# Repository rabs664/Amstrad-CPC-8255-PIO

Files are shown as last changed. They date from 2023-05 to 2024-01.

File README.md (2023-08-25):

# Amstrad CPC 8255 PIO
Simple 8255 PIO board compatible with the Amstrad CPC and MX4 connector.

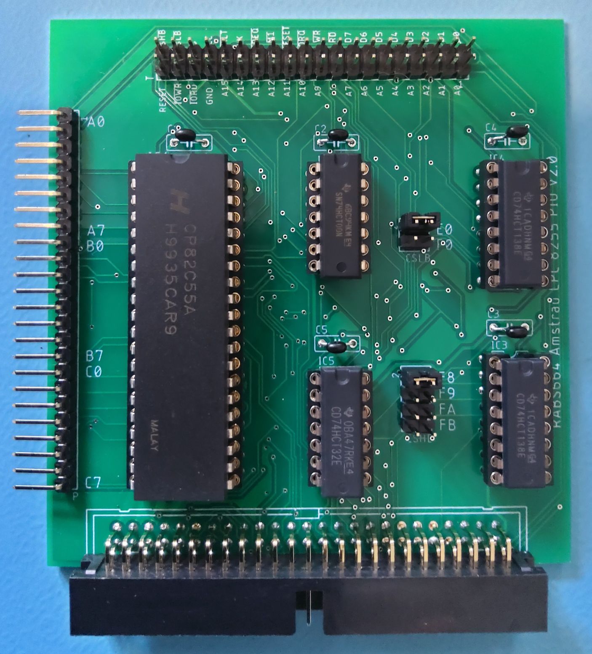
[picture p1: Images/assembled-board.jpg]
readme_pic1


## Objective
Prototyping board to Learn about the 8255 PIO, and how to write Z80 assembly using an Amstrad CPC.

## Background
Part of a number of modular cards using Z80 associated peripherals and the Amstrad CPC.

## Backplane
[CPC Amstrad Expansion Backplane by revaldinho](https://github.com/revaldinho/cpc_ram_expansion/wiki/CPC-Expansion-Backplane)

## IO Addressing
The IO Address can be selected using two sets of jumpers (CS_HB and CS_LB), supporting the following base address.

* F8E0 and F8F0
* F9E0 and F9F0
* FAE0 and FAF0
* FBE0 and FBF0

See [CPC Wiki IO Port Summary](https://www.cpcwiki.eu/index.php/I/O_Port_Summary) for a list of known IO ports used on the Amstrad CPC.

## Testing
The 8255 PIO board has been built and has been tested on an Amstrad CPC 6128.

## PCBs
PCBs are available from [Seeed Studio V2.0](https://www.seeedstudio.com/Amstrad-CPC-8255-PIO-g-1393845) or [Seeed Studio V3.1](https://www.seeedstudio.com/Simple-8255-PIO-board-compatible-with-the-Amstrad-CPC-and-MX4-connector-V3--g-1396645)

## Components
This [Digi-Key List](https://www.digikey.co.uk/en/mylists/list/ZWWIHRPLO7 ) contains all components excluding the 8255 which was purchased from EBay.

Note the right angled header for the port connections was not available at the time of producing this list but all other components were in stock for shipping immediately.

## Assembler
[RASM](https://github.com/EdouardBERGE/rasm)

## Resources
[Zed80 Website](http://zed80.com/Z80-RETRO/index_Home.html)

[CPCWiki](https://www.cpcwiki.eu/index.php/Main_Page)

Z80 Application by James W Coffron ISBN 0-89588-094-6

## Acknowledgements
[@revaldinho](https://github.com/revaldinho)

Don Prefontaine 

Peter Murray

[@EdouardBERGE](https://github.com/EdouardBERGE)

# Release History
## Version 2.0
* First Release
## Version 3.1
* KiCad created version of PCB.

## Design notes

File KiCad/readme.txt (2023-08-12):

This folder contains files associated with the use of KiCad to create the schematics and PCB.

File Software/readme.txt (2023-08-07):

This folder contains software associated with the Amstrad CPC 8255 PIO.

piotst04.bas is a test program written in BASIC.

piotst02.asm is an equivalent program written in Z80 Assembly (using RASM) and using CPC Firmware routines. piotst02.dsk is the disk created from this.

very-quick-test.txt contains some simple instructions to undertake a very quick test to see if the PIO is working.

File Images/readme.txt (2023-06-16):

This folder contains some images of the Amstrad CPC 8255 PIO board and associated test programs.

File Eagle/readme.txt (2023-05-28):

This folder contains files associated with the use of Eagle to create the schematics and PCB.

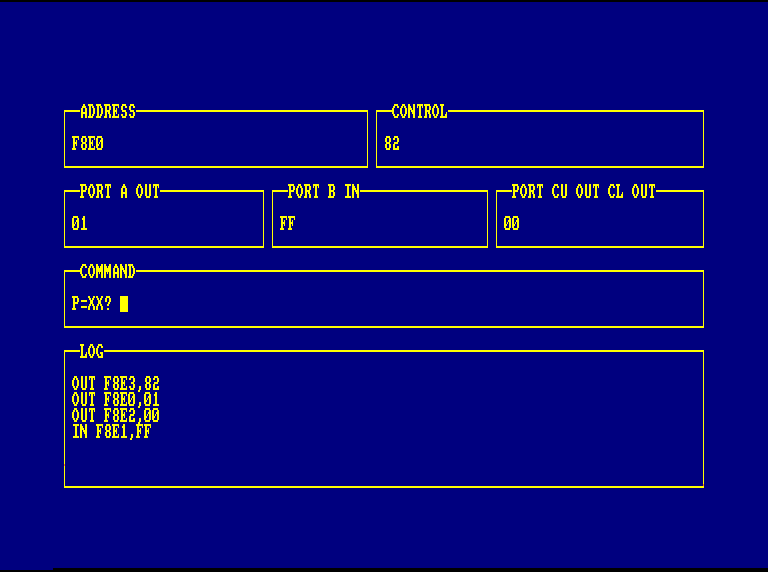
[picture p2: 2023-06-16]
Images/PIOTST04.png

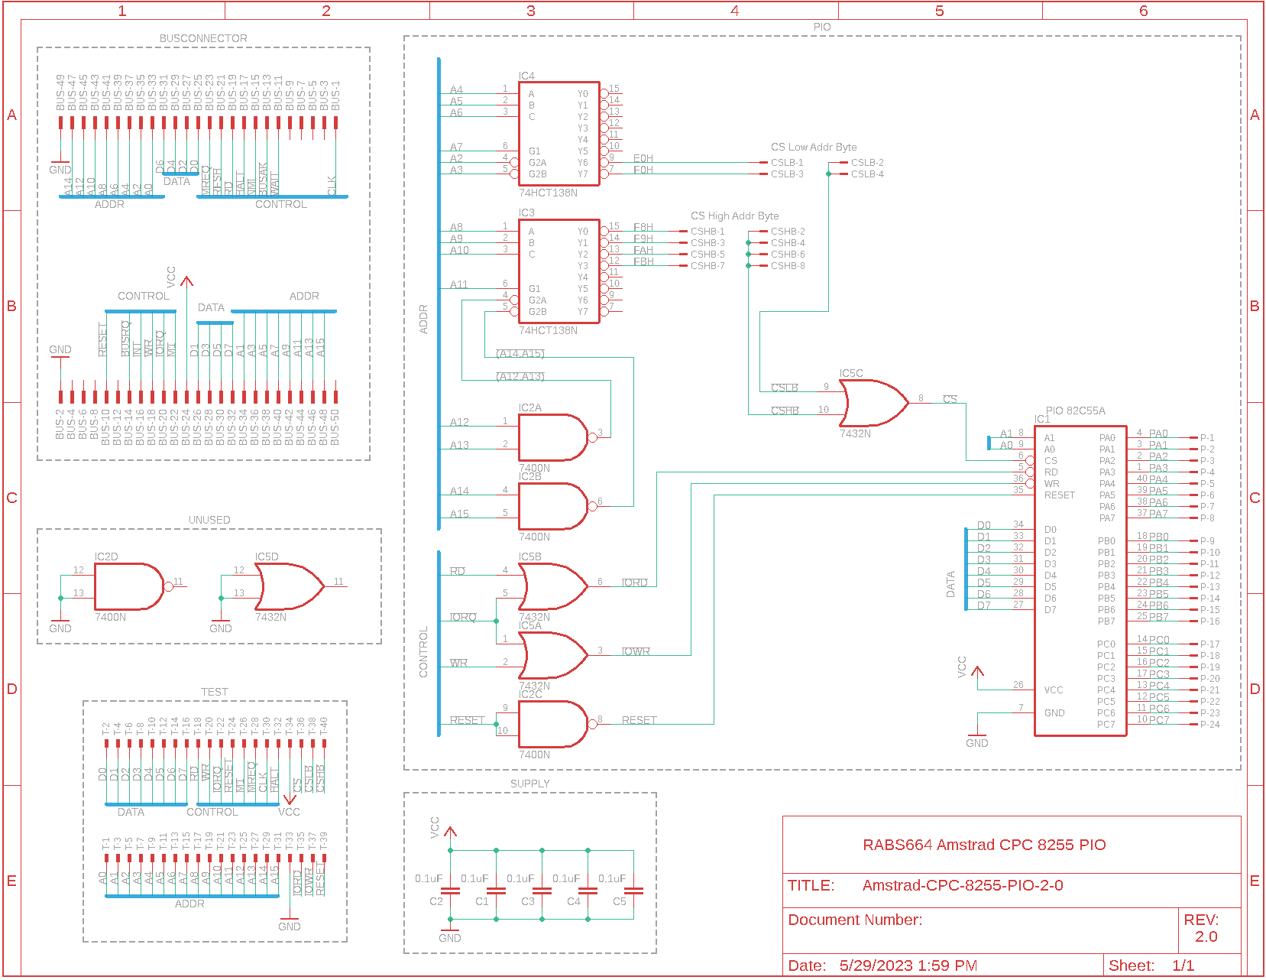
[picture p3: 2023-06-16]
Images/Amstrad-CPC-8255-PIO-2-0-SCH.png

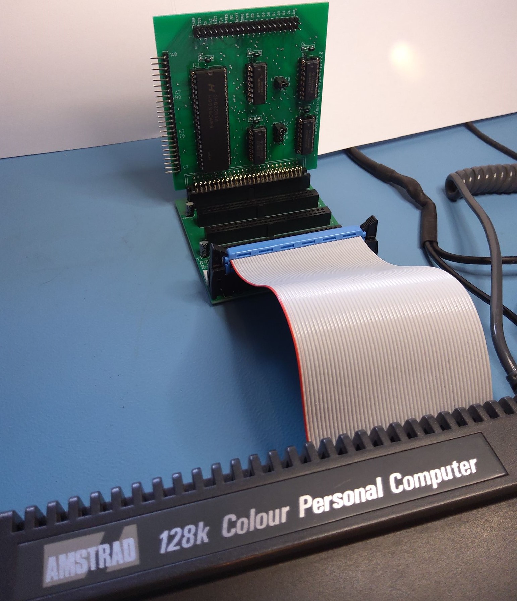
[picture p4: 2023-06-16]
Images/board-connected-to-6128.jpg

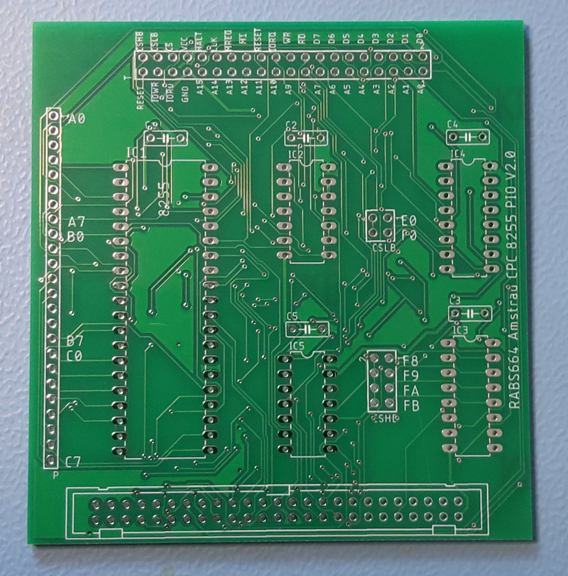
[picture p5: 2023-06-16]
Images/bare-board.jpg

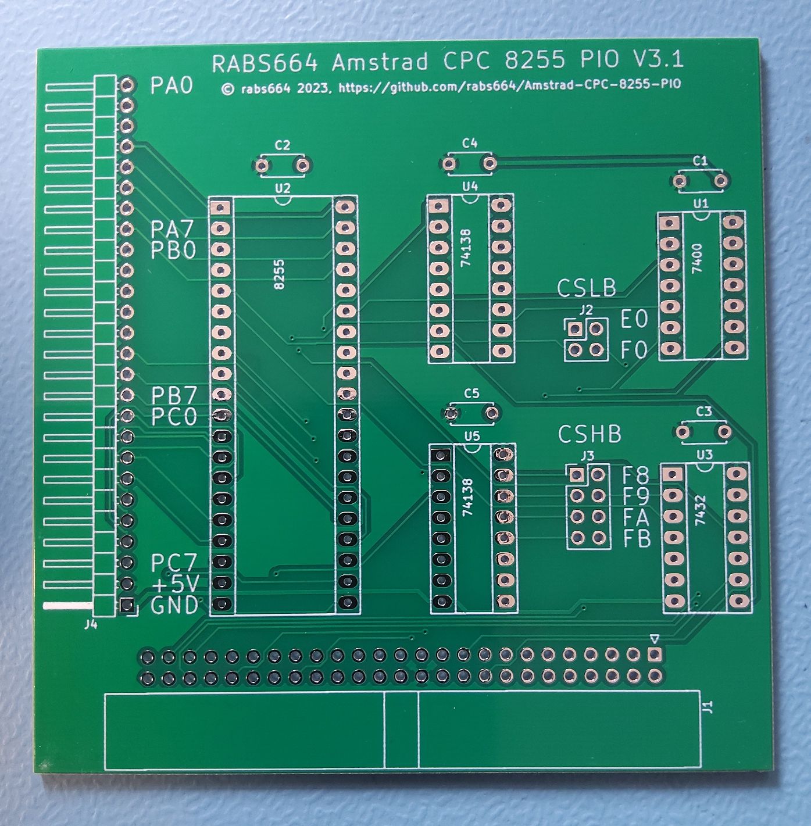
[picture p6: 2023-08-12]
Images/bare-board-v3-1.jpg

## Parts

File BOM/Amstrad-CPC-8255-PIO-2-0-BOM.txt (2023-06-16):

Part Value          Device          Package        Description                            MF          MPN            OC_FARNELL OC_NEWARK POPULARITY SPICEPREFIX
BUS  2550-          2550-           PAK100/2500-50 3M (TM) Pak 100 4-Wall Header                                     unknown    unknown   0          X          
C1   0.1uF          C-EU050-025X075 C050-025X075   CAPACITOR, European symbol                                                             29         C          
C2   0.1uF          C-EU050-025X075 C050-025X075   CAPACITOR, European symbol                                                             29         C          
C3   0.1uF          C-EU050-025X075 C050-025X075   CAPACITOR, European symbol                                                             29         C          
C4   0.1uF          C-EU050-025X075 C050-025X075   CAPACITOR, European symbol                                                             29         C          
C5   0.1uF          C-EU050-025X075 C050-025X075   CAPACITOR, European symbol                                                             29         C          
CSHB TSW-104-07-G-D TSW-104-07-G-D  TSW-104-XX-G-D THROUGH-HOLE .025" SQ POST HEADER      Samtec Inc. TSW-104-07-G-D                                            
CSLB TSW-102-07-G-D TSW-102-07-G-D  TSW-102-XX-G-D THROUGH-HOLE .025" SQ POST HEADER      Samtec Inc. TSW-102-07-G-D                                            
IC1                 82C55A          DIL40          MICROCOMPUTER/PERIPHERAL DEVICE        INTERSIL    IP82C55AZ      1562050    79K6939   0                     
IC2  7400N          7400N           DIL14          Quad 2-input NAND gate                                                                 0                     
IC3  74HCT138N      74HCT138N       DIL16          3-line to 8-line DECODER/DEMULTIPLEXER                                                 0                     
IC4  74HCT138N      74HCT138N       DIL16          3-line to 8-line DECODER/DEMULTIPLEXER                                                 0                     
IC5  7432N          7432N           DIL14          Quad 2-input OR gate                                                                   0                     
P    TSW-124-07-G-S TSW-124-07-G-S  TSW-124-XX-G-S THROUGH-HOLE .025" SQ POST HEADER      Samtec Inc. TSW-124-07-G-S                                            
T    TSW-120-07-G-D TSW-120-07-G-D  TSW-120-XX-G-D THROUGH-HOLE .025" SQ POST HEADER      Samtec Inc. TSW-120-07-G-D

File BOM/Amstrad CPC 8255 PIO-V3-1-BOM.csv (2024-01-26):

# | Reference | Qty | Value | Footprint | DNP
1 | C1, C2, C3, C4, C5 | 5 | 100nF | Capacitor_THT:C_Disc_D5.0mm_W2.5mm_P5.00mm
2 | J1 | 1 | Conn_02x25_Odd_Even | Connector_IDC:IDC-Header_2x25_P2.54mm_Horizontal
3 | J2 | 1 | Conn_02x02_Odd_Even | Connector_PinHeader_2.54mm:PinHeader_2x02_P2.54mm_Vertical
4 | J3 | 1 | Conn_02x04_Odd_Even | Connector_PinHeader_2.54mm:PinHeader_2x04_P2.54mm_Vertical
5 | J4 | 1 | Conn_01x26 | Connector_PinHeader_2.54mm:PinHeader_1x26_P2.54mm_Horizontal
6 | U1 | 1 | 74HCT00 | Package_DIP:DIP-14_W7.62mm_Socket_LongPads
7 | U2 | 1 | 82C55A | Package_DIP:DIP-40_W15.24mm_Socket_LongPads
8 | U3 | 1 | 74HCT32 | Package_DIP:DIP-14_W7.62mm_Socket_LongPads
9 | U4, U5 | 2 | 74HCT138 | Package_DIP:DIP-16_W7.62mm_Socket_LongPads

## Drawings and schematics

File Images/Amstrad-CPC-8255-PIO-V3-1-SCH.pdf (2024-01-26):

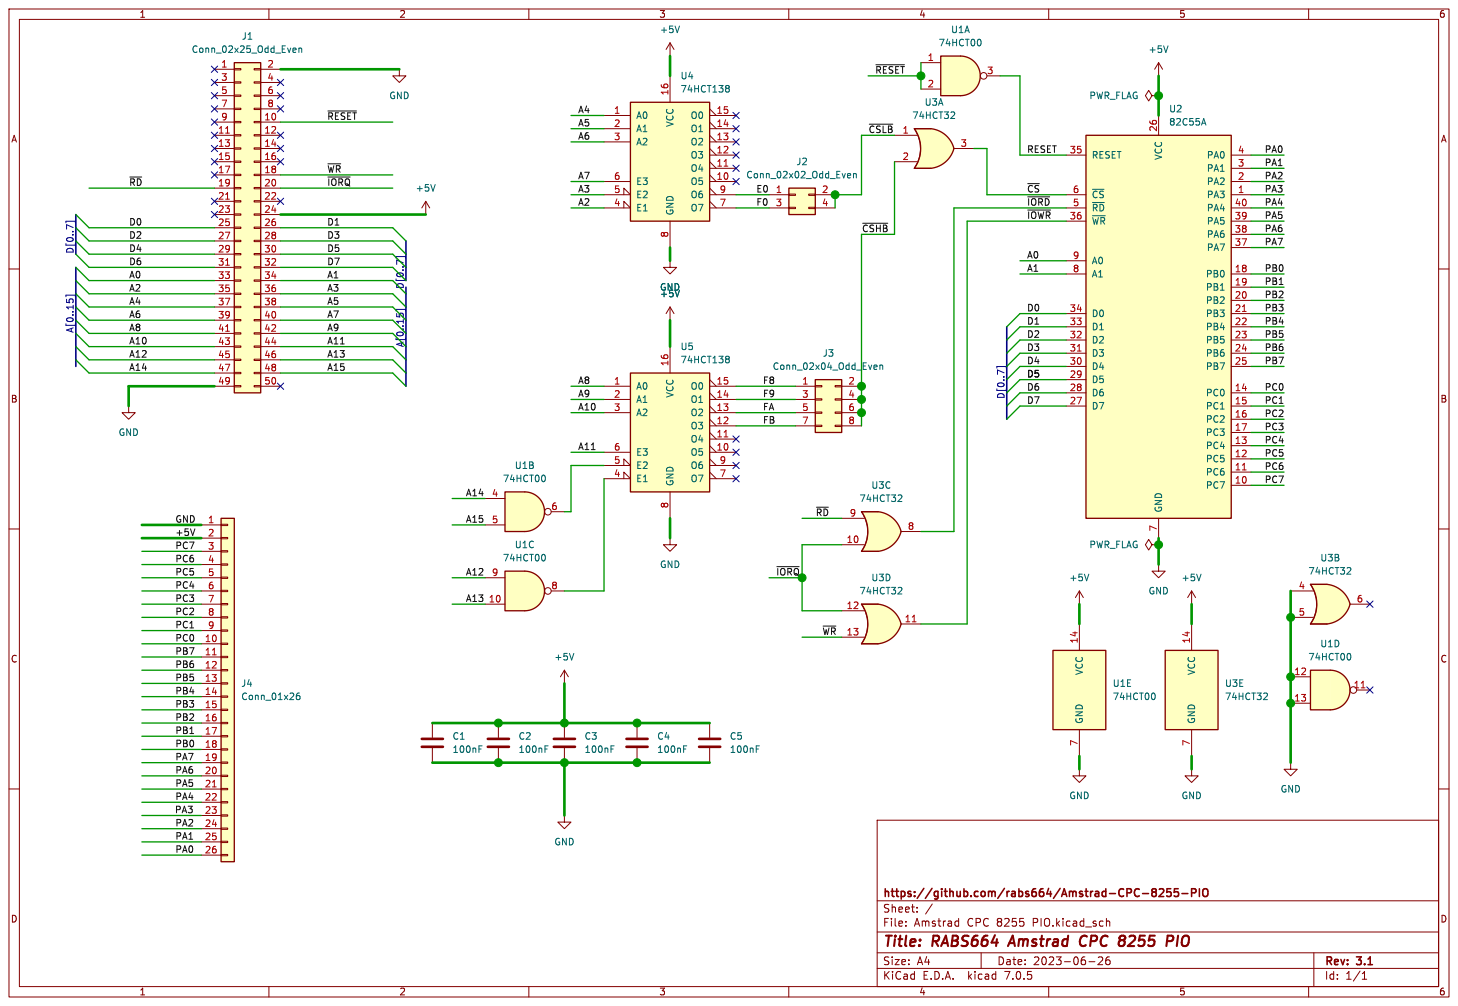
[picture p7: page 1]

Id: 1/1 Title: RABS664 Amstrad CPC 8255 PIO

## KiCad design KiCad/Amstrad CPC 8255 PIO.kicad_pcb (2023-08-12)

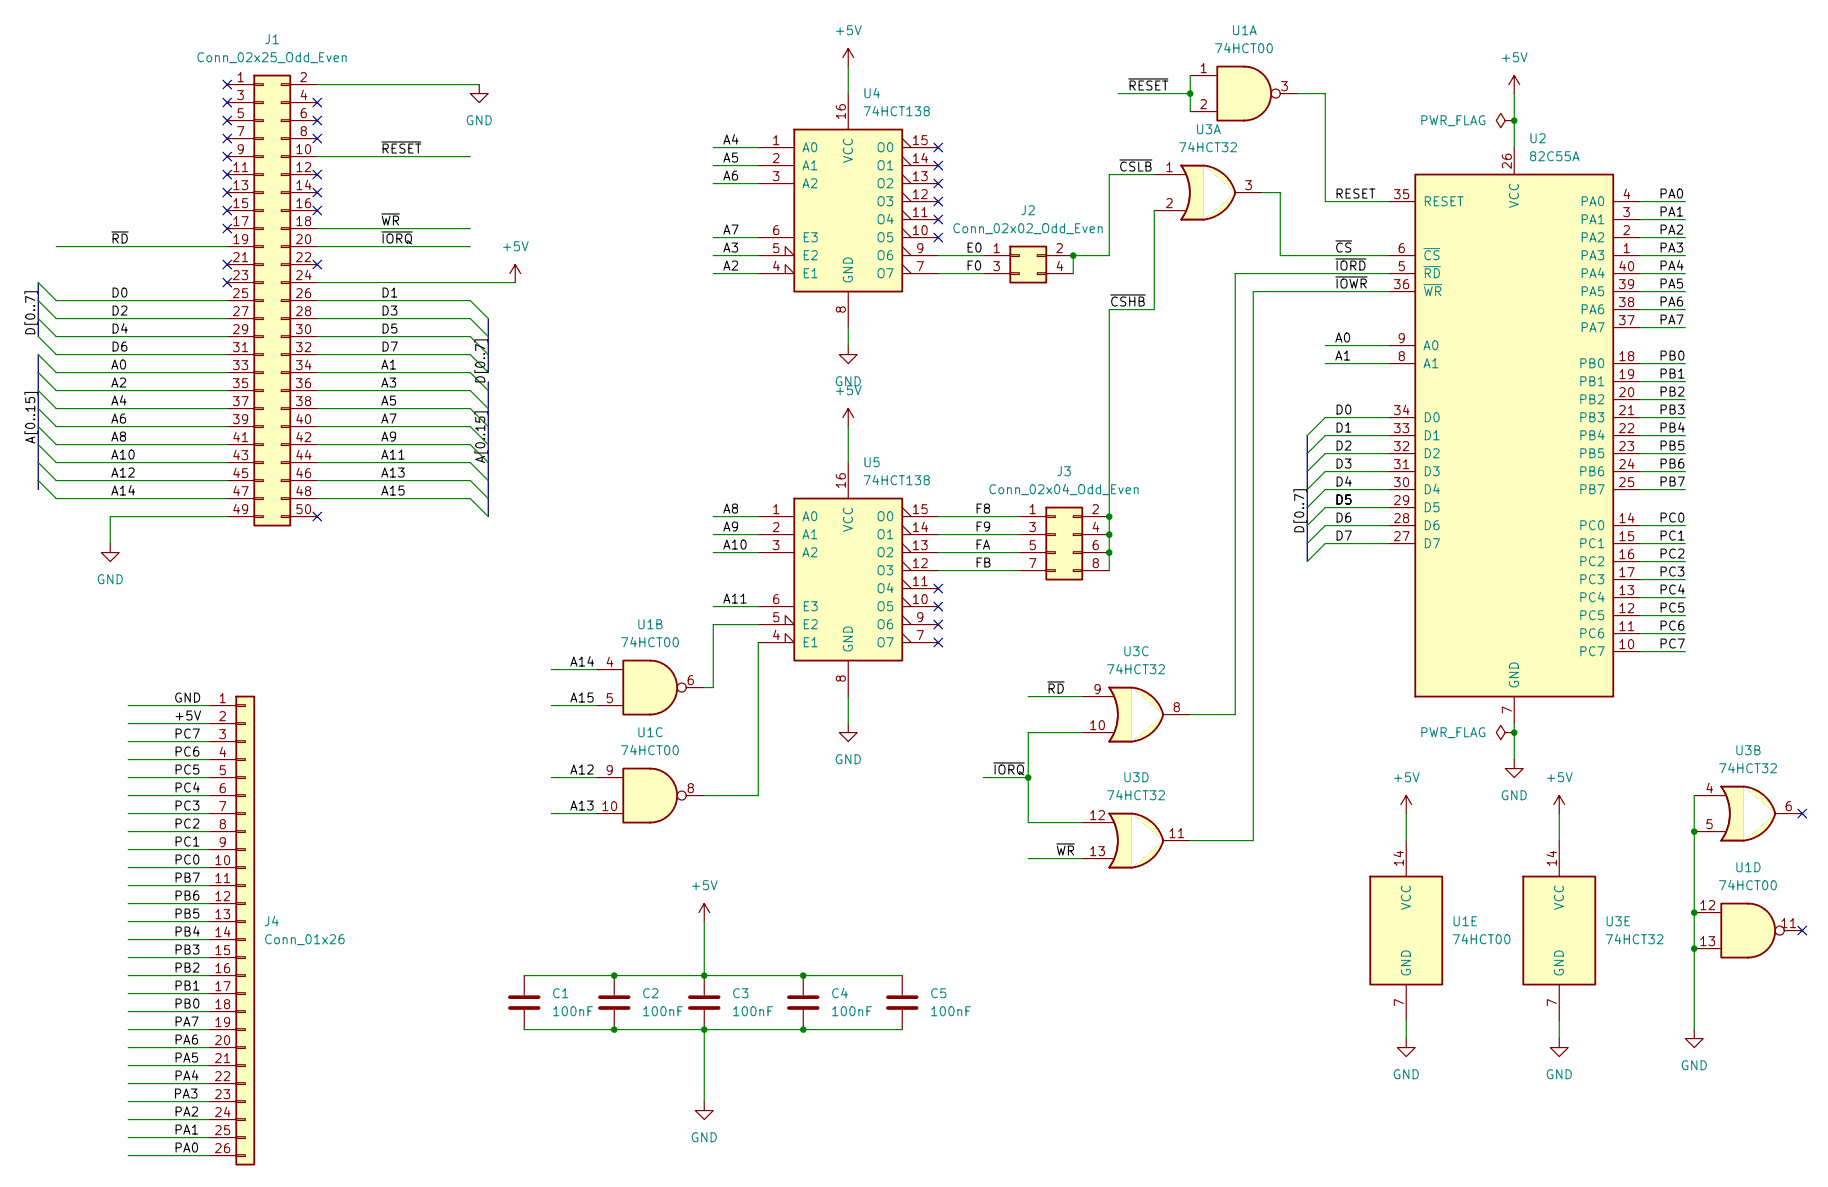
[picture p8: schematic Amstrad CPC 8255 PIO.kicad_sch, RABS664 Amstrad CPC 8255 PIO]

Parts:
C1, C2, C3, C4, C5: 100nF; C_Disc_D5.0mm_W2.5mm_P5.00mm; DigiKey 56-K104K15X7RF53H5G-ND
J1: Conn_02x25_Odd_Even; IDC-Header_2x25_P2.54mm_Horizontal; DigiKey 3M157291-ND
J2: Conn_02x02_Odd_Even; PinHeader_2x02_P2.54mm_Vertical
J3: Conn_02x04_Odd_Even; PinHeader_2x04_P2.54mm_Vertical
J4: Conn_01x26; PinHeader_1x26_P2.54mm_Horizontal
U1: 74HCT00; DIP-14_W7.62mm_Socket_LongPads; DigiKey 296-2081-5-ND
U2: 82C55A; DIP-40_W15.24mm_Socket_LongPads
U3: 74HCT32; DIP-14_W7.62mm_Socket_LongPads; Digikey 296-2112-5-ND
U4, U5: 74HCT138; DIP-16_W7.62mm_Socket_LongPads; DigiKey 296-2091-5-ND

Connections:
+5V: C1.1, C2.1, C3.1, C4.1, C5.1, J1.24, J4.2, U1.14 (VCC), U2.26 (VCC), U3.14 (VCC), U4.16 (VCC), U5.16 (VCC)
/A0: J1.33, U2.9 (A0)
/A1: J1.34, U2.8 (A1)
/A2: J1.35, U4.4 (E1)
/A3: J1.36, U4.5 (E2)
/A4: J1.37, U4.1 (A0)
/A5: J1.38, U4.2 (A1)
/A6: J1.39, U4.3 (A2)
/A7: J1.40, U4.6 (E3)
/A8: J1.41, U5.1 (A0)
/A9: J1.42, U5.2 (A1)
/A10: J1.43, U5.3 (A2)
/A11: J1.44, U5.6 (E3)
/A12: J1.45, U1.9
/A13: J1.46, U1.10
/A14: J1.47, U1.4
/A15: J1.48, U1.5
/D0: J1.25, U2.34 (D0)
/D1: J1.26, U2.33 (D1)
/D2: J1.27, U2.32 (D2)
/D3: J1.28, U2.31 (D3)
/D4: J1.29, U2.30 (D4)
/D5: J1.30, U2.29 (D5)
/D6: J1.31, U2.28 (D6)
/D7: J1.32, U2.27 (D7)
/E0: J2.1, U4.9 (O6)
/F0: J2.3, U4.7 (O7)
/F8: J3.1, U5.15 (O0)
/F9: J3.3, U5.14 (O1)
/FA: J3.5, U5.13 (O2)
/FB: J3.7, U5.12 (O3)
/PA0: J4.26, U2.4 (PA0)
/PA1: J4.25, U2.3 (PA1)
/PA2: J4.24, U2.2 (PA2)
/PA3: J4.23, U2.1 (PA3)
/PA4: J4.22, U2.40 (PA4)
/PA5: J4.21, U2.39 (PA5)
/PA6: J4.20, U2.38 (PA6)
/PA7: J4.19, U2.37 (PA7)
/PB0: J4.18, U2.18 (PB0)
/PB1: J4.17, U2.19 (PB1)
/PB2: J4.16, U2.20 (PB2)
/PB3: J4.15, U2.21 (PB3)
/PB4: J4.14, U2.22 (PB4)
/PB5: J4.13, U2.23 (PB5)
/PB6: J4.12, U2.24 (PB6)
/PB7: J4.11, U2.25 (PB7)
/PC0: J4.10, U2.14 (PC0)
/PC1: J4.9, U2.15 (PC1)
/PC2: J4.8, U2.16 (PC2)
/PC3: J4.7, U2.17 (PC3)
/PC4: J4.6, U2.13 (PC4)
/PC5: J4.5, U2.12 (PC5)
/PC6: J4.4, U2.11 (PC6)
/PC7: J4.3, U2.10 (PC7)
/RESET: U1.3, U2.35 (RESET)
/~CSHB: J3.2, J3.4, J3.6, J3.8, U3.2
/~CSLB: J2.2, J2.4, U3.1
/~CS: U2.6 (~CS), U3.3
/~IORD: U2.5 (~RD), U3.8
/~IORQ: J1.20, U3.10, U3.12
/~IOWR: U2.36 (~WR), U3.11
/~RD: J1.19, U3.9
/~RESET: J1.10, U1.1, U1.2
/~WR: J1.18, U3.13
GND: C1.2, C2.2, C3.2, C4.2, C5.2, J1.2, J1.49, J4.1, U1.7 (GND), U1.12, U1.13, U2.7 (GND), U3.4, U3.5, U3.7 (GND), U4.8 (GND), U5.8 (GND)
unnamed: U1.8, U5.4 (E1)
unnamed: U1.6, U5.5 (E2)

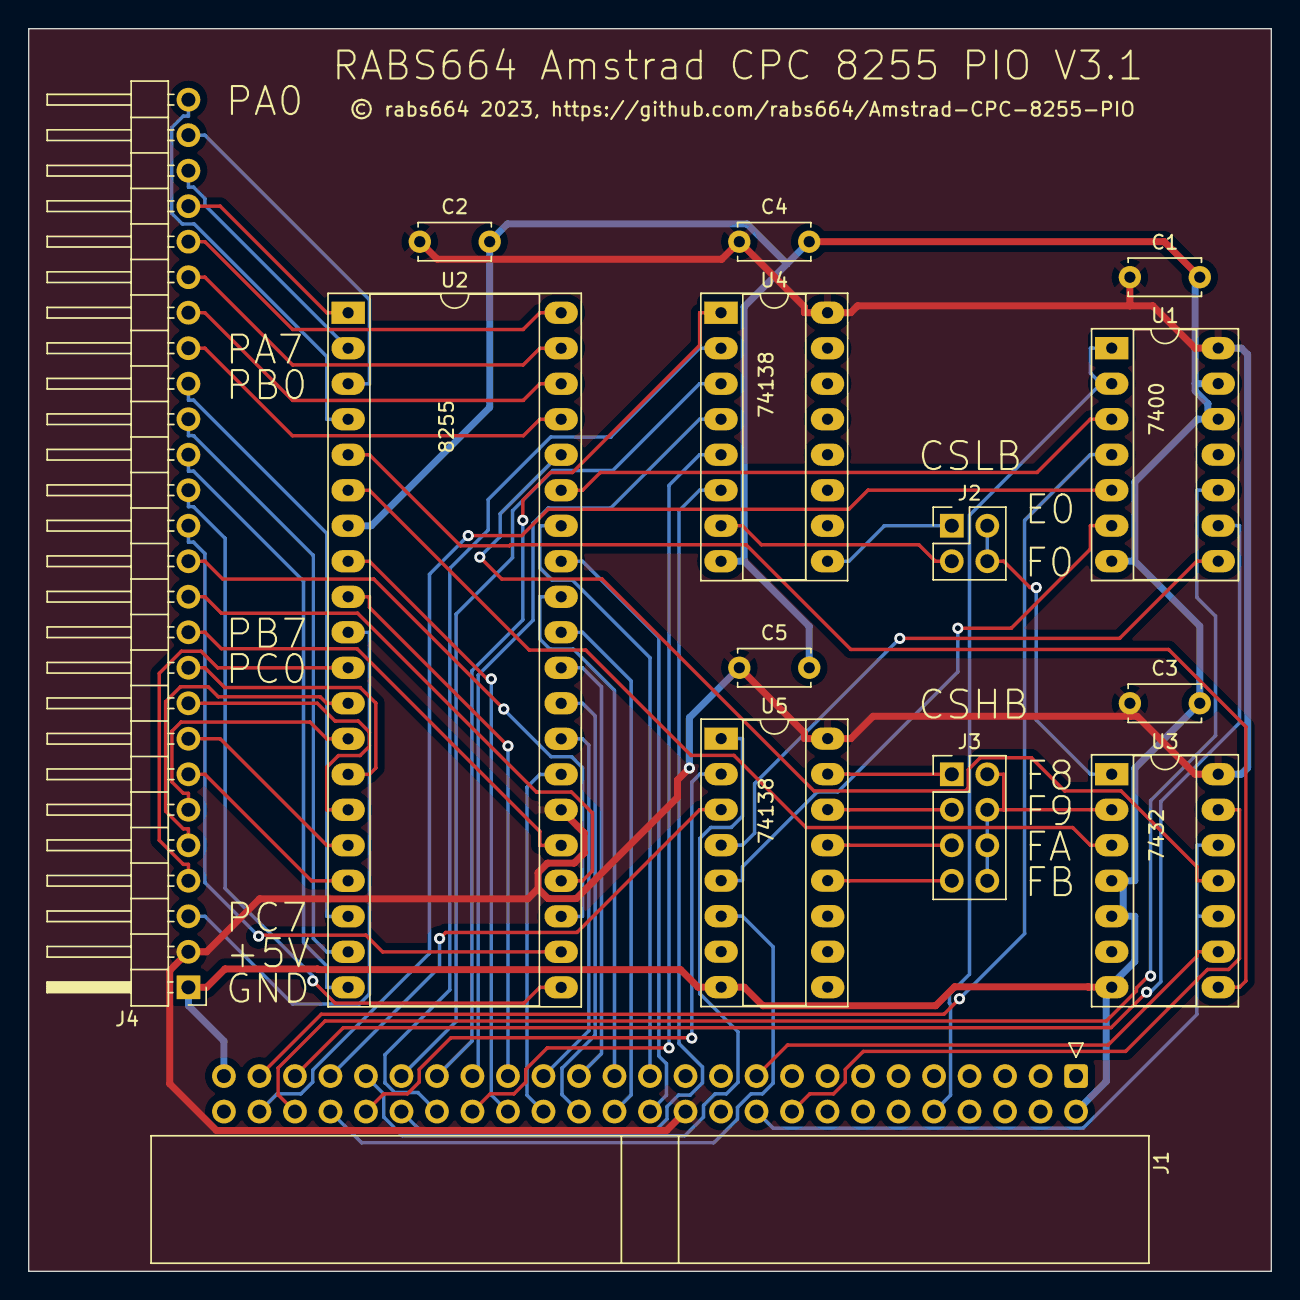
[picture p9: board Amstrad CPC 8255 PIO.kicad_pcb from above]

Board: 2 copper layers, 88.9 x 88.9 mm, 14 parts (0 on the bottom side), 68 nets.

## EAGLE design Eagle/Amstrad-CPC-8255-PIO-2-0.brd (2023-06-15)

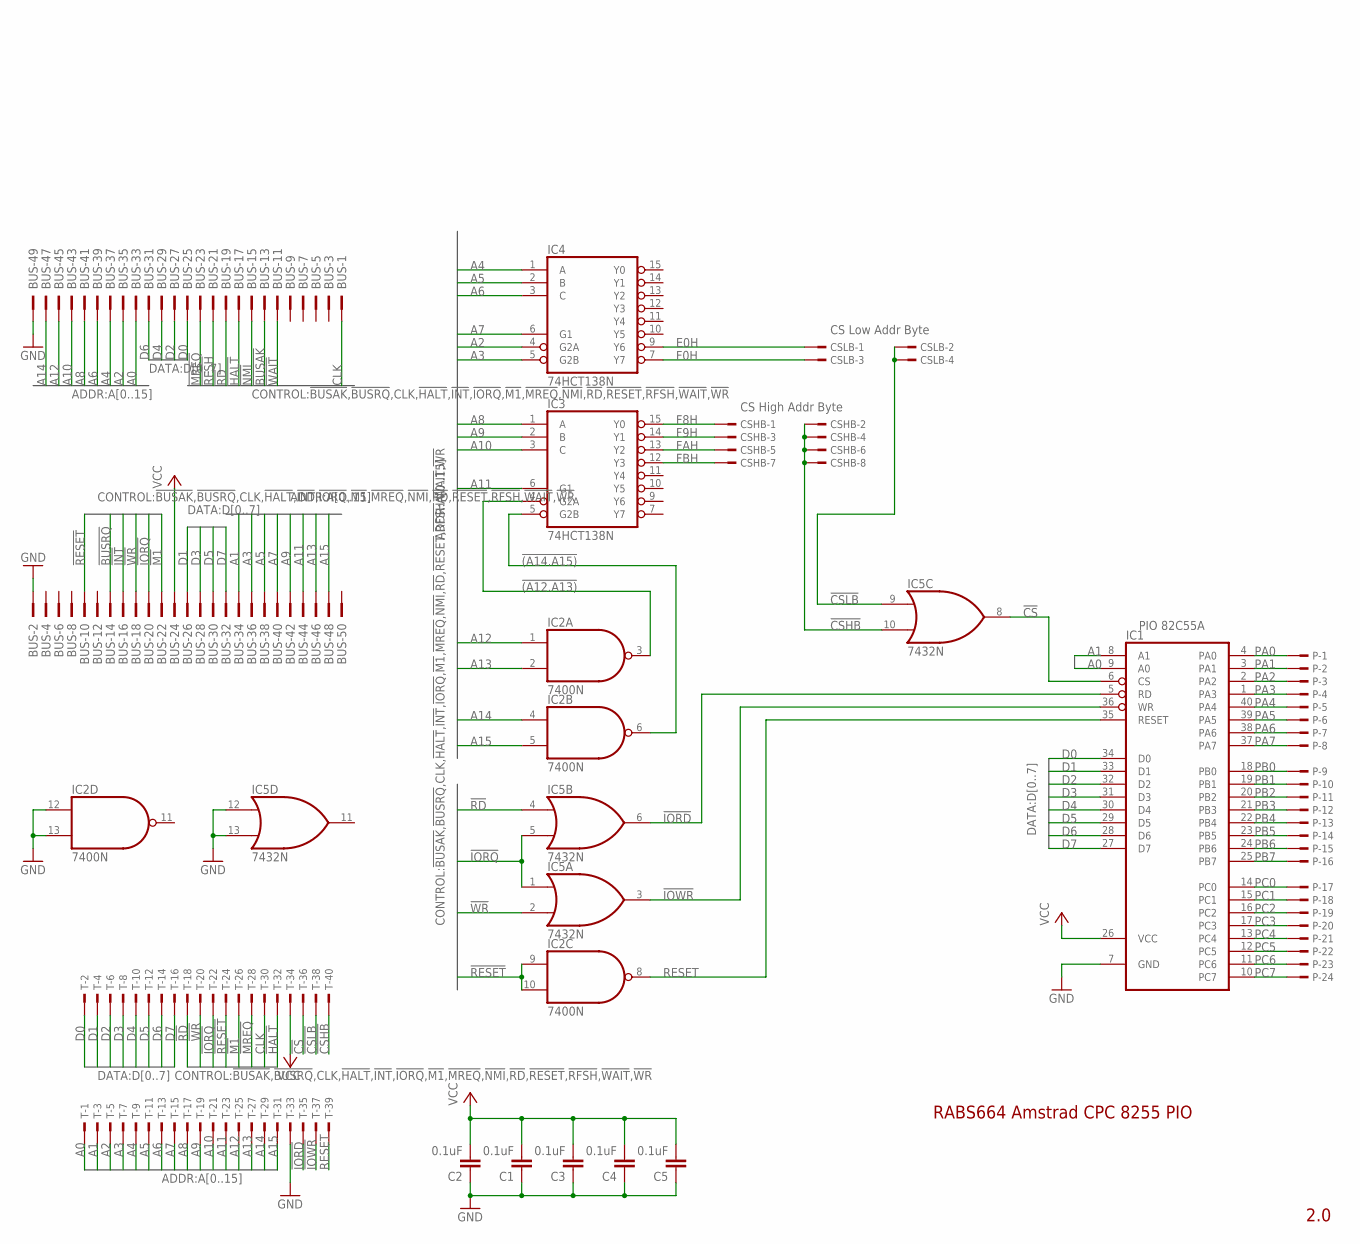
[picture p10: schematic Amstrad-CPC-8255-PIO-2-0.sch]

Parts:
BUS: 2550-; PAK100/2500-50
C1, C2, C3, C4, C5: 0.1uF; C050-025X075
CSHB: TSW-104-07-G-D; TSW-104-XX-G-D
CSLB: TSW-102-07-G-D; TSW-102-XX-G-D
IC1: 82C55A; DIL40
IC2: 7400N; DIL14
IC3, IC4: 74HCT138N; DIL16
IC5: 7432N; DIL14
P: TSW-124-07-G-S; TSW-124-XX-G-S
T: TSW-120-07-G-D; TSW-120-XX-G-D

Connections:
!(A12.A13): IC2.3 (O), IC3.4 (G2A)
!(A14.A15): IC2.6 (O), IC3.5 (G2B)
!BUSAK: BUS.13
!BUSRQ: BUS.14
!CS: IC1.6 (CS), IC5.8 (O), T.36
!CSHB: CSHB.2, CSHB.4, CSHB.6, CSHB.8, IC5.10 (I1), T.40
!CSLB: CSLB.2, CSLB.4, IC5.9 (I0), T.38
!HALT: BUS.17, T.32
!INT: BUS.16
!IORD: IC1.5 (RD), IC5.6 (O), T.35
!IORQ: BUS.20, IC5.1 (I0), IC5.5 (I1), T.22
!IOWR: IC1.36 (WR), IC5.3 (O), T.37
!M1: BUS.22, T.26
!MREQ: BUS.23, T.28
!NMI: BUS.15
!RD: BUS.19, IC5.4 (I0), T.18
!RESET: BUS.10, IC2.9 (I0), IC2.10 (I1), T.24
!RFSH: BUS.21
!WAIT: BUS.11
!WR: BUS.18, IC5.2 (I1), T.20
A0: BUS.33, IC1.9 (A0), T.1
A1: BUS.34, IC1.8 (A1), T.3
A2: BUS.35, IC4.4 (G2A), T.5
A3: BUS.36, IC4.5 (G2B), T.7
A4: BUS.37, IC4.1 (A), T.9
A5: BUS.38, IC4.2 (B), T.11
A6: BUS.39, IC4.3 (C), T.13
A7: BUS.40, IC4.6 (G1), T.15
A8: BUS.41, IC3.1 (A), T.17
A9: BUS.42, IC3.2 (B), T.19
A10: BUS.43, IC3.3 (C), T.21
A11: BUS.44, IC3.6 (G1), T.23
A12: BUS.45, IC2.1 (I0), T.25
A13: BUS.46, IC2.2 (I1), T.27
A14: BUS.47, IC2.4 (I0), T.29
A15: BUS.48, IC2.5 (I1), T.31
CLK: BUS.1, T.30
D0: BUS.25, IC1.34 (D0), T.2
D1: BUS.26, IC1.33 (D1), T.4
D2: BUS.27, IC1.32 (D2), T.6
D3: BUS.28, IC1.31 (D3), T.8
D4: BUS.29, IC1.30 (D4), T.10
D5: BUS.30, IC1.29 (D5), T.12
D6: BUS.31, IC1.28 (D6), T.14
D7: BUS.32, IC1.27 (D7), T.16
E0H: CSLB.1, IC4.9 (Y6)
F0H: CSLB.3, IC4.7 (Y7)
F8H: CSHB.1, IC3.15 (Y0)
F9H: CSHB.3, IC3.14 (Y1)
FAH: CSHB.5, IC3.13 (Y2)
FBH: CSHB.7, IC3.12 (Y3)
GND: BUS.2, BUS.49, C1.1, C2.1, C3.1, C4.1, C5.1, IC1.7 (GND), IC2.7 (GND), IC2.12 (I0), IC2.13 (I1), IC3.8 (GND), IC4.8 (GND), IC5.7 (GND), IC5.12 (I0), IC5.13 (I1), T.33
PA0: IC1.4 (PA0), P.1
PA1: IC1.3 (PA1), P.2
PA2: IC1.2 (PA2), P.3
PA3: IC1.1 (PA3), P.4
PA4: IC1.40 (PA4), P.5
PA5: IC1.39 (PA5), P.6
PA6: IC1.38 (PA6), P.7
PA7: IC1.37 (PA7), P.8
PB0: IC1.18 (PB0), P.9
PB1: IC1.19 (PB1), P.10
PB2: IC1.20 (PB2), P.11
PB3: IC1.21 (PB3), P.12
PB4: IC1.22 (PB4), P.13
PB5: IC1.23 (PB5), P.14
PB6: IC1.24 (PB6), P.15
PB7: IC1.25 (PB7), P.16
PC0: IC1.14 (PC0), P.17
PC1: IC1.15 (PC1), P.18
PC2: IC1.16 (PC2), P.19
PC3: IC1.17 (PC3), P.20
PC4: IC1.13 (PC4), P.21
PC5: IC1.12 (PC5), P.22
PC6: IC1.11 (PC6), P.23
PC7: IC1.10 (PC7), P.24
RESET: IC1.35 (RESET), IC2.8 (O), T.39
VCC: BUS.24, C1.2, C2.2, C3.2, C4.2, C5.2, IC1.26 (VCC), IC2.14 (VCC), IC3.16 (VCC), IC4.16 (VCC), IC5.14 (VCC), T.34

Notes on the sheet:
2.0
RABS664 Amstrad CPC 8255 PIO
PIO 82C55A
CS High Addr Byte
CS Low Addr Byte

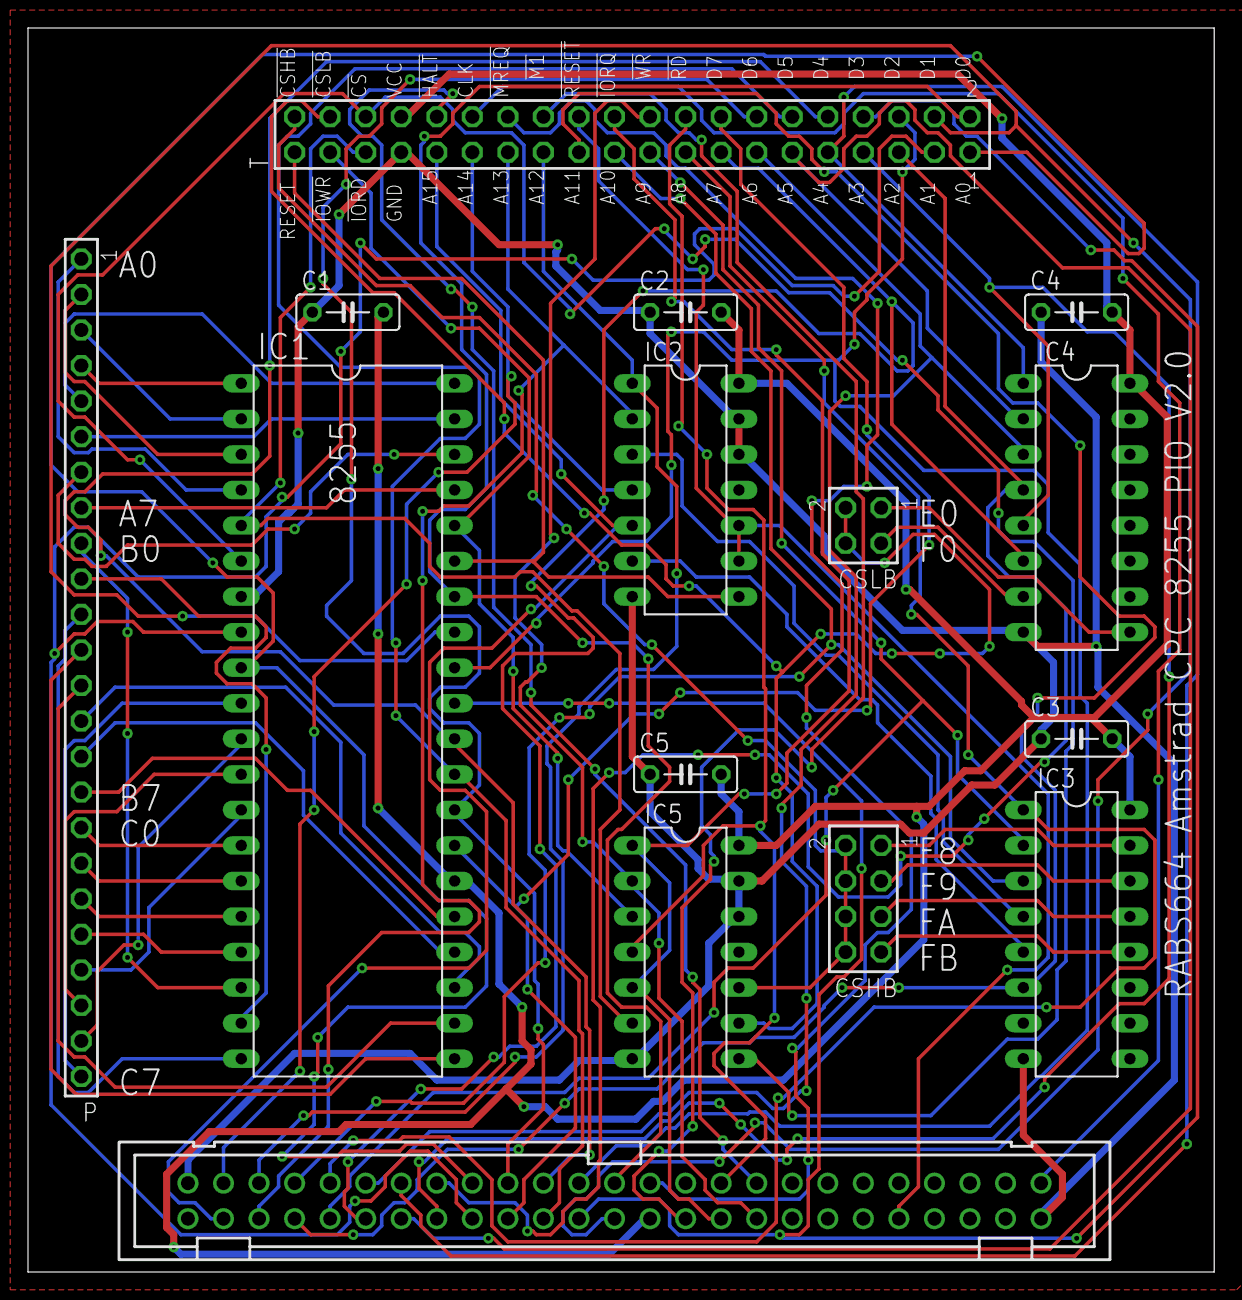
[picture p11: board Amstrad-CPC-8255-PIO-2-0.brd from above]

Board: 2 copper layers, 84.8 x 88.9 mm, 15 parts (0 on the bottom side), 72 nets.

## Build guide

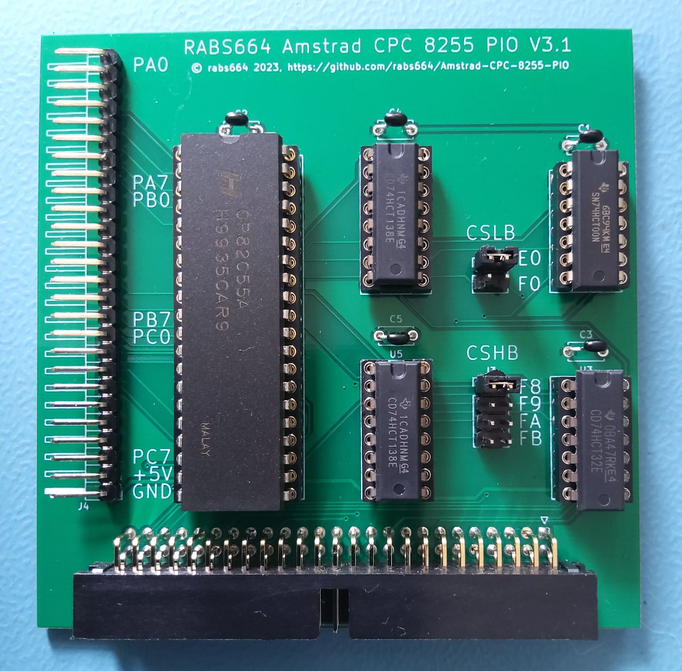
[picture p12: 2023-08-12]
Images/assembled-board-v3-1.jpg

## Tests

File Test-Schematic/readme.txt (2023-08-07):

This folder contains an Eagle schematic for a simple test harness.

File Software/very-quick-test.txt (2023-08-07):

Very quick test.

For base address &F8E0.

At the BASIC prompt enter.

OUT &F8E3,&80

Then measure the voltage on PA0 which should be 0V.

At the BASIC prompt enter.

OUT &F8E0,&01

Then measure the voltage on PA0 which should be 5V.

At the BASIC prompt enter.

OUT &F8E0,&00

Then measure the voltage on PA0 which should be 0V.

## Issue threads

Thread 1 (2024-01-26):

BOM for version 3.1 of board not included in repository

rabs664, 2024-01-26:
Version 3.1 of the board was produced using KiCad an so the labelling is quite different. There is a BOM and schematic pic for version 2.0 but not 3.1.

rabs664, 2024-01-26:
Uploaded jpg of schematic and BOM for version 3.1 (both exported from KiCad)

Closed 2024-01-26.

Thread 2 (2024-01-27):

Test Schematic for breadboard shows HC ICs should be HCT

rabs664, 2024-01-27:
The picture of the test schematic in images shows two 74HC245N ICs should be 74HCT245N.

rabs664, 2024-01-27:
Corrected and new images with corrected HCT logic family uploaded and the old file deleted.

Closed 2024-01-27.

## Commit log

2023-05-28 Add files via upload
    First Release, changed name of files from Z80 PIO to 8255 PIO.
    [8255_pio_1_4.brd, 8255_pio_1_4.sch]
2023-08-25 Update README.md
    Updated Seeed Studio References for PCBs
2024-01-26 Uploaded KiCad 7.0 schematic for version 3.1
    Noted that there was not a jpg image for version 3.1 board which was created in KiCad 7.0
2024-01-26 Added BOM from KiCAD 7.0 for version 3.1
    Noted that BOM only existed for version 2.0
    [Amstrad CPC 8255 PIO-V3-1-BOM.csv]
2024-01-27 Pictures of Test Breaboard and v3.1
    Some picture of the test breadboard used and when connected to the V3.1 PIO board.

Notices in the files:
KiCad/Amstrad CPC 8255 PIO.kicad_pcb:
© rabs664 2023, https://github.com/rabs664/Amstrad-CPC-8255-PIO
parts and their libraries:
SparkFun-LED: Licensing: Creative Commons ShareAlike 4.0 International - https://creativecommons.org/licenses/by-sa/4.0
